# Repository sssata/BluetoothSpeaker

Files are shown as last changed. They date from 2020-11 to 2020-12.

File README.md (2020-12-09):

# BluetoothSpeaker
A diy omnidirectional bluetooth speaker.

Completed 2020.

# Features
- 2-Way speaker with passive radiator design for bass response down to 40 Hz
- Woofer: Tang Band W5-1138SMF 5" Paper Cone Subwoofer
- Tweeter: Dayton Audio DC28F-8 1-1/8" Silk Tweeter
- DSP equalizer for tuned frequency response and FIR crossover for phase coherence
- Omnidirectional radiaton pattern for consistent sound in different rooms/environments
- Battery Powered with Battery Level indicator
- Charging via USB-C PD

# Gallery
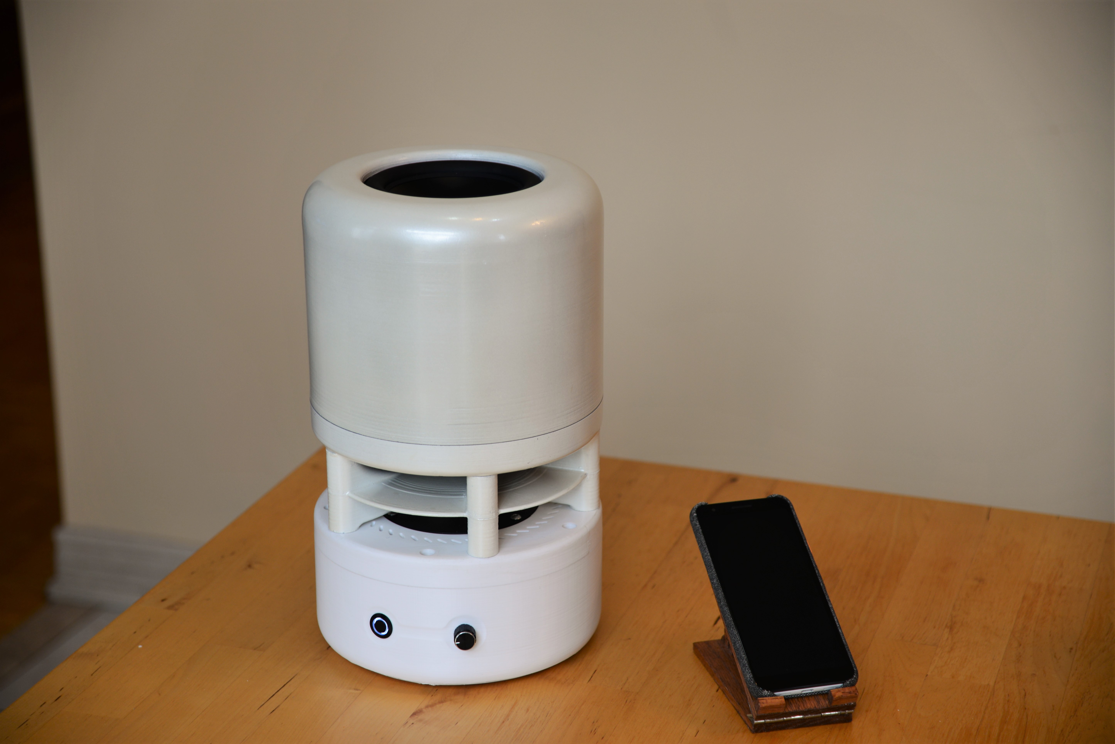
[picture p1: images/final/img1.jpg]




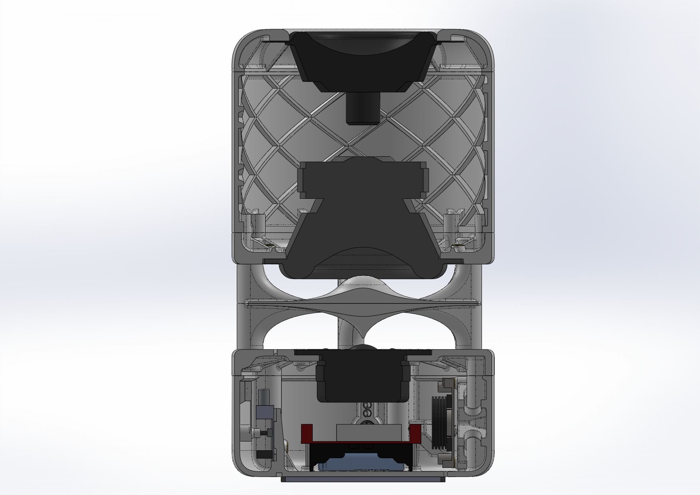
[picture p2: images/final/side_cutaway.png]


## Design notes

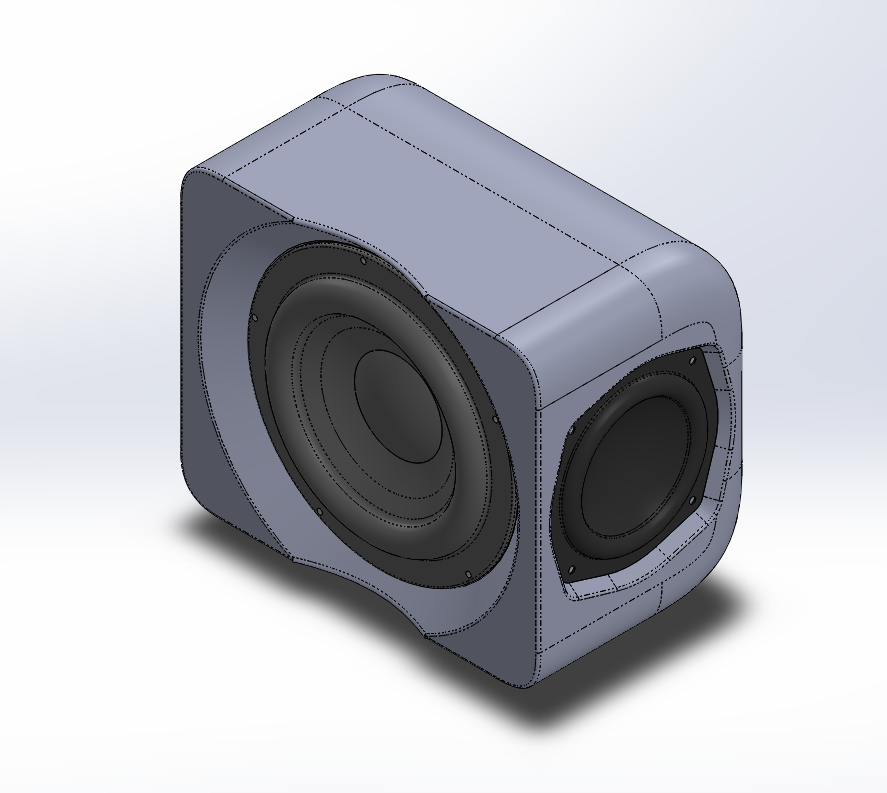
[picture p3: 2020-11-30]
images/concept/concept2.png

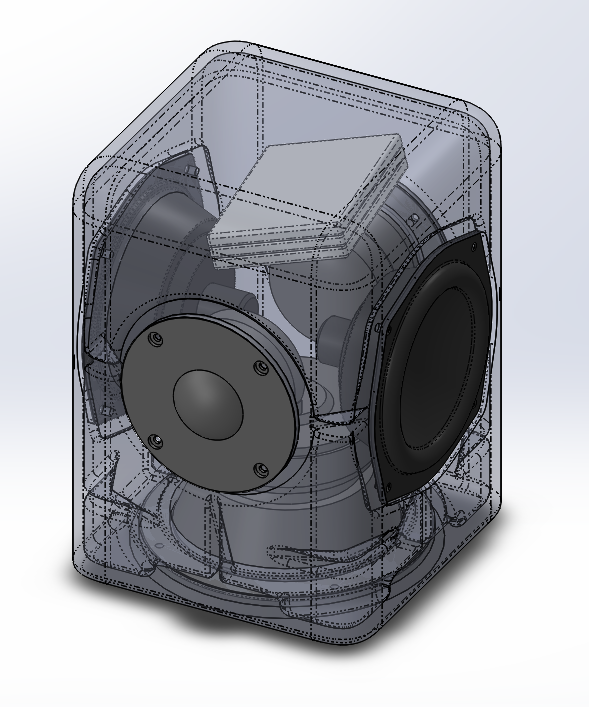
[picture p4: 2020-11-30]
images/concept/concept1.png

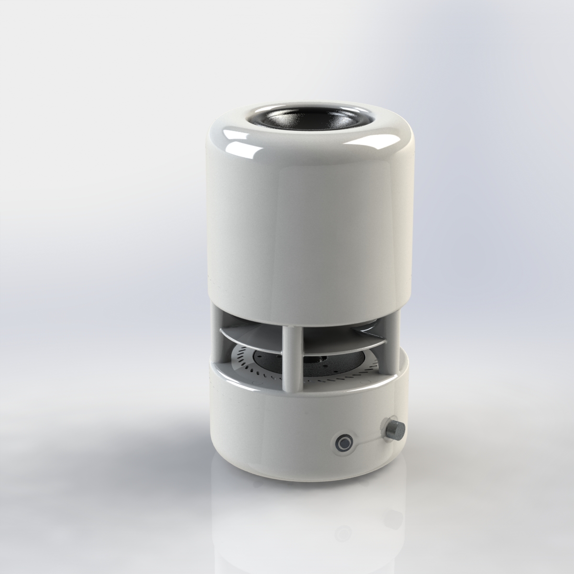
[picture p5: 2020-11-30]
images/final/full.JPG

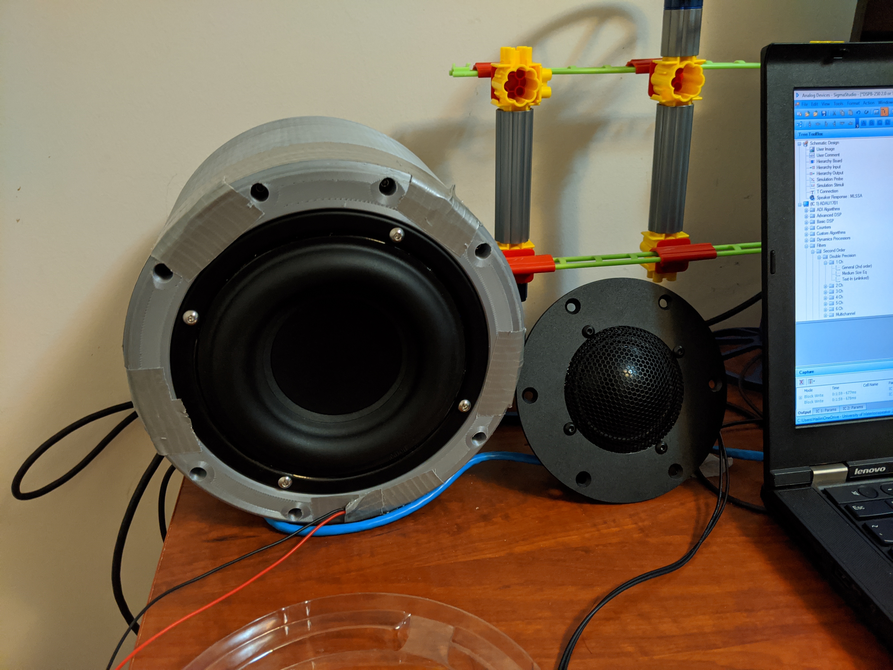
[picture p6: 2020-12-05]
images/prototyping/woofer.jpg

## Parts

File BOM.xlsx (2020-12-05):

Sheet: 900
Assembly Number | 900
Assembly Name | Top Level Assembly
BOM
Part Number | Part Name | Qty
003 | reflector | 1
800 | base assembly | 1
801 | tweeter plate assembly | 1
802 | woofer plate assembly | 1
803 | woofer cover assembly | 1
112 | M5x80 SHCS | 5
156 | base pad | 1
121 | M4x20 SHCS | 10
122 | M5x20 SHCS | 5

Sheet: 800
Assembly Number | 800
Assembly Name | Base Assembly
BOM
Part Number | Part Name | Qty
001 | Base | 1
151 | U16F2 Switch | 1
152 | U8M Switch | 1
153 | Volume Knob | 1
154 | 5mm LED | 4
100 | M3 Insert | 7
150 | 10K POT | 1
300 | Bluetooth Board | 1
301 | Dayton Audio DSPB-250 | 1
302 | Dayton Audio KAB-BE | 1
021 | USBC Port Cover | 1
020 | USBC Port | 1
118 | M3x12 BHCS | 6

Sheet: 801
Assembly Number | 801
Assembly Name | Tweeter Plate Assembly
BOM
Part Number | Part Name | Qty
002 | tweeter plate | 1
007 | Tweeter Plate Plug | 5
401 | Dayton Audio DC28F-8 | 1
102 | M5 Insert | 5
115 | M5 Nut | 3
116 | M4x12 BHCS | 3

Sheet: 802
Assembly Number | 802
Assembly Name | Tweeter Plate Assembly
BOM
Part Number | Part Name | Qty
011 | Woofer Cover Bottom | 1
400 | Dayton Audio 105-PR | 1
101 | M4 Insert | 10
117 | M4x6 BHCS | 4

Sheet: 803
Assembly Number | 803
Assembly Name | Tweeter Plate Assembly
BOM
Part Number | Part Name | Qty
010 | Woofer Plate | 1
402 | Tang Band W5-1138SMF | 1
101 | M4 Insert | 4
102 | M5 Insert | 5
116 | M4x12 BHCS | 4

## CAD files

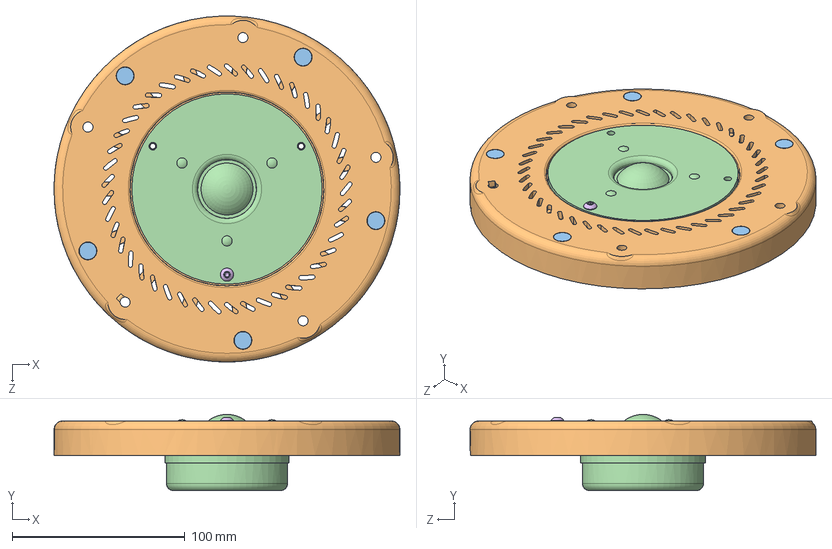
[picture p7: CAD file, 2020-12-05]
CAD/801 tweeter plate assy.SLDASM
200.0 x 44.1 x 200.0 mm
102 M5 Insert x 5
002 tweeter plate
007 tweeter plate plug x 5
401 Dayton Audio DC28F-8 tweeter
115 M4 NUT x 3
socket button head cap screw_am

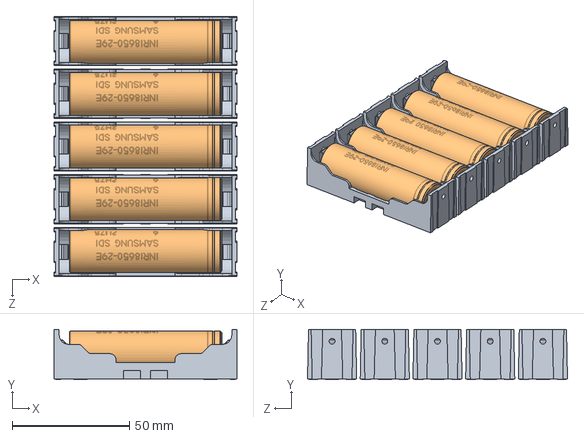
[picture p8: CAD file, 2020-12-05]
CAD/302 Dayton Audio KAB-BE Battery Board.SLDASM
77.9 x 21.4 x 111.0 mm
single 18650 battery holder x 5
Samsung INR18650-29R x 5

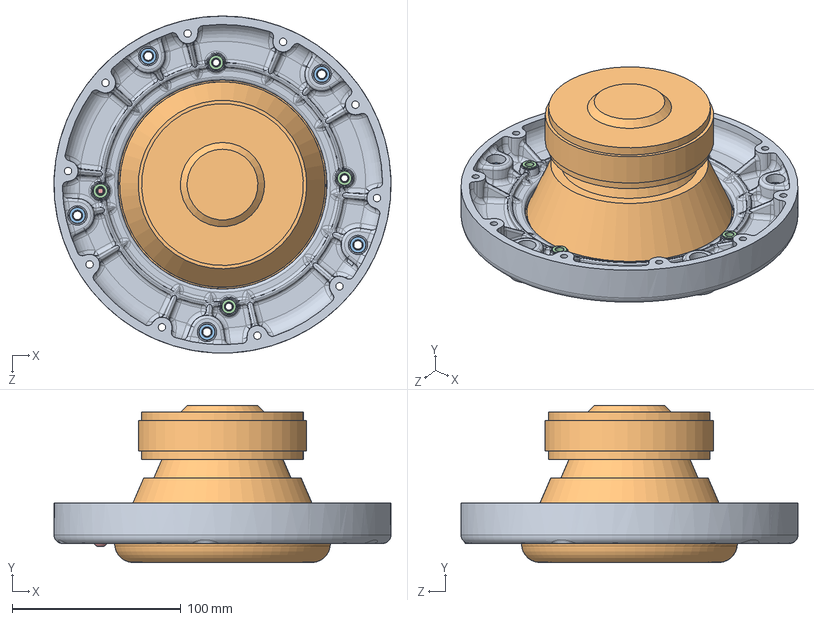
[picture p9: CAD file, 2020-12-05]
CAD/803 woofer plate assy.SLDASM
200.0 x 93.2 x 199.9 mm
010 top woofer plate
402 Tang Band W5-1138SMF
102 M5 Insert x 5
101 M4 Insert x 4
socket button head cap screw_am

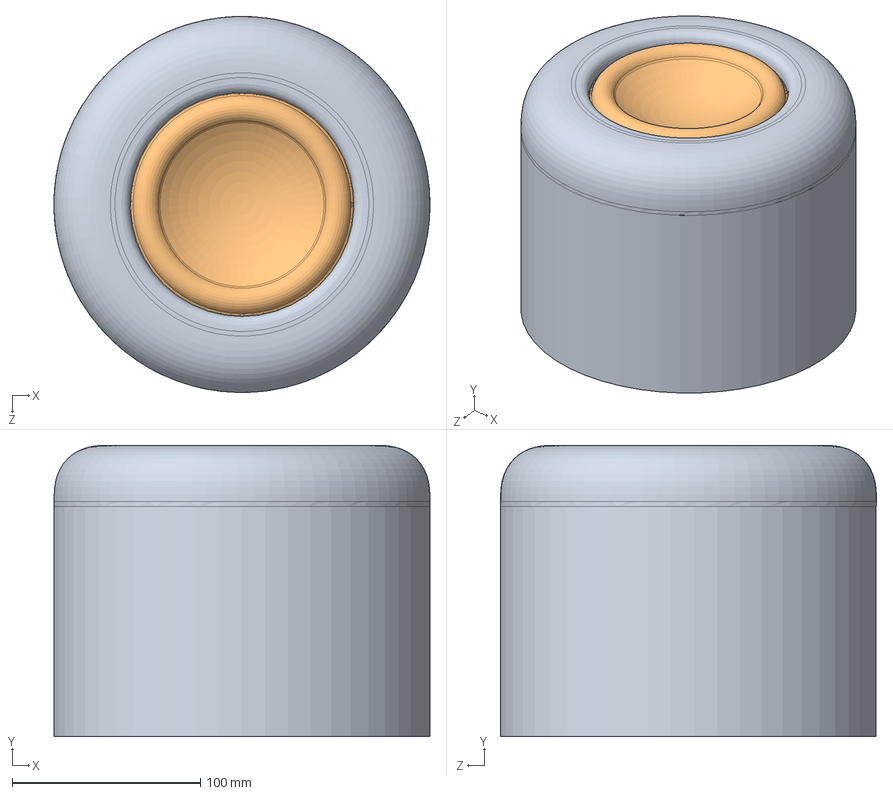
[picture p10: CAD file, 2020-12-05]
CAD/802 woofer cover assy.SLDASM
200.0 x 155.0 x 200.0 mm
011 woofer cover bottom
400 Dayton Audio 105-PR 4inch
101 M4 Insert x 10
socket button head cap screw_am x 4

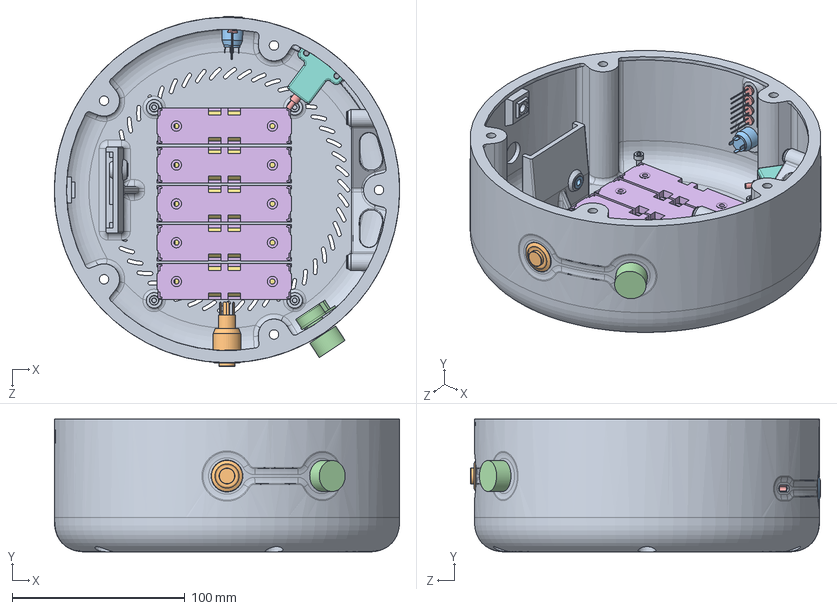
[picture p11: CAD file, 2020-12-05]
CAD/800 base assembly.SLDASM
200.0 x 77.0 x 202.7 mm
001 Base
151 U16F2 Switch
100 M3 Insert x 7
150 10K Pot
020 USBC port
single 18650 battery holder x 5
Samsung INR18650-29R x 5
021 USBC port cover
113 M3x25 SHCS x 4
114 M3 NUT x 4
152 U8M Switch
153 Volume Knob
154 5mm LED x 4

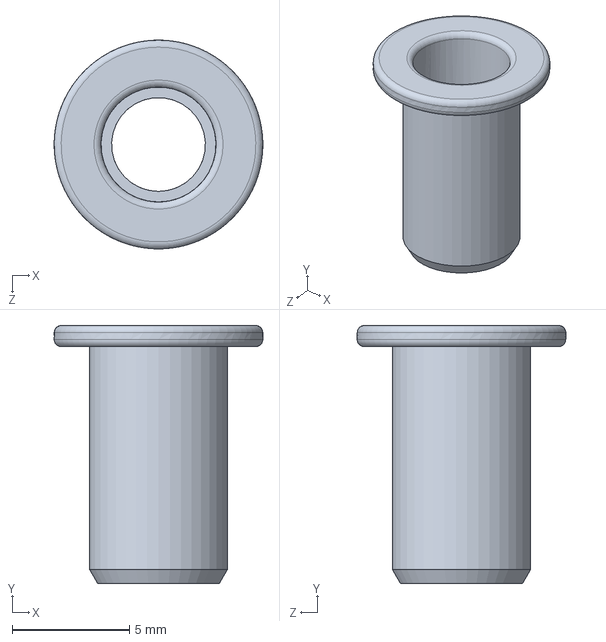
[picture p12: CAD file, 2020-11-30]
CAD3/101 M4 Insert.SLDPRT
8.90 x 11.0 x 8.90 mm

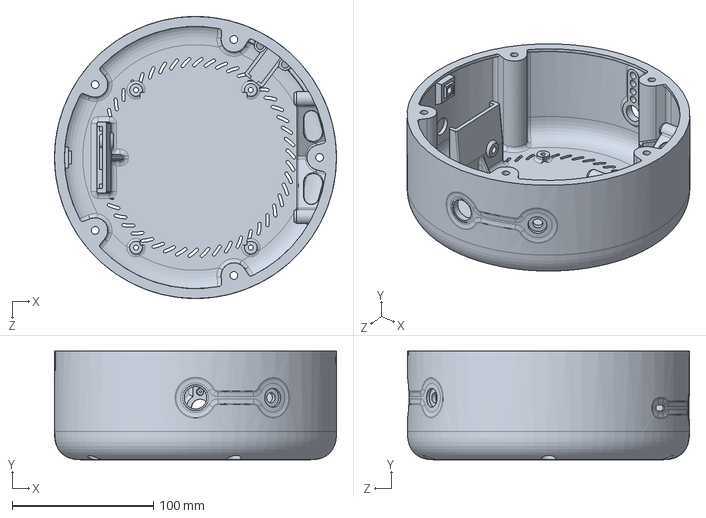
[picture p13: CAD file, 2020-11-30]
CAD3/001 Base.SLDPRT
200.0 x 77.0 x 200.0 mm

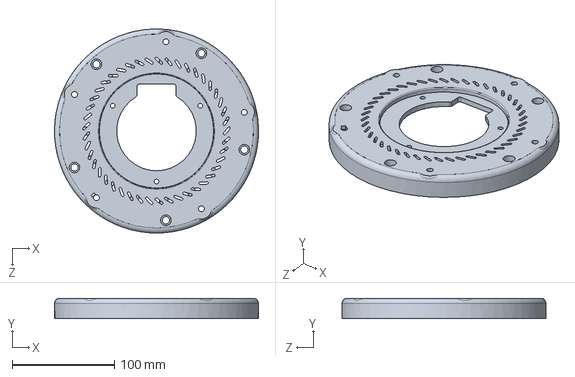
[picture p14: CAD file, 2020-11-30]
CAD3/002 tweeter plate.sldprt
200.0 x 20.0 x 200.0 mm

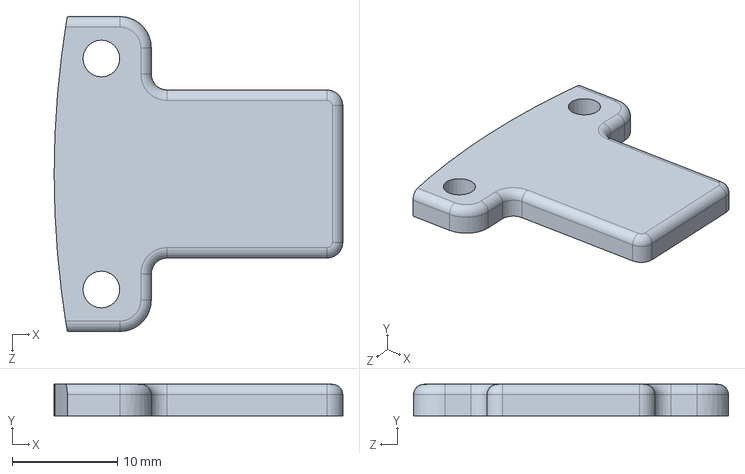
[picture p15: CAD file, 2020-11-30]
CAD3/021 USBC port cover.SLDPRT
27.5 x 3.00 x 30.0 mm

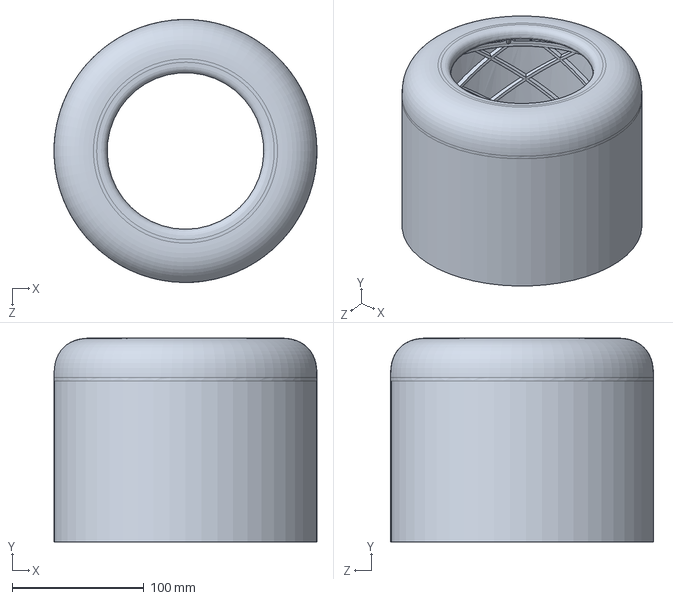
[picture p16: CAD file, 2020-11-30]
CAD3/011 woofer cover bottom.SLDPRT
200.0 x 155.0 x 200.0 mm

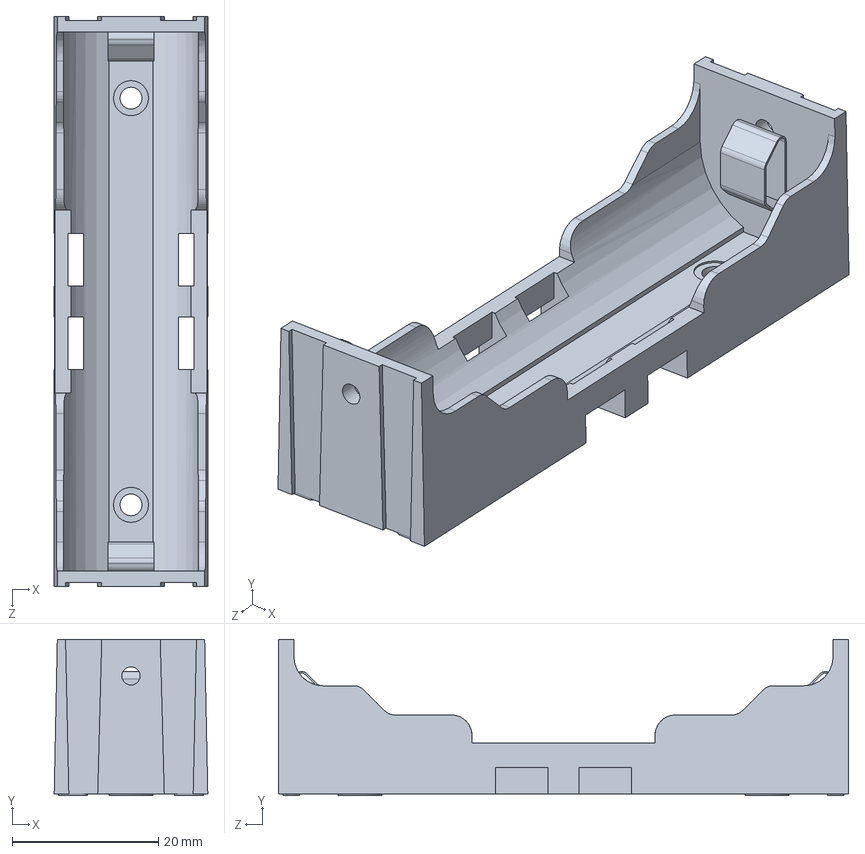
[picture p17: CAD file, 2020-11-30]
CAD3/single 18650 battery holder.SLDPRT
21.0 x 21.4 x 77.9 mm

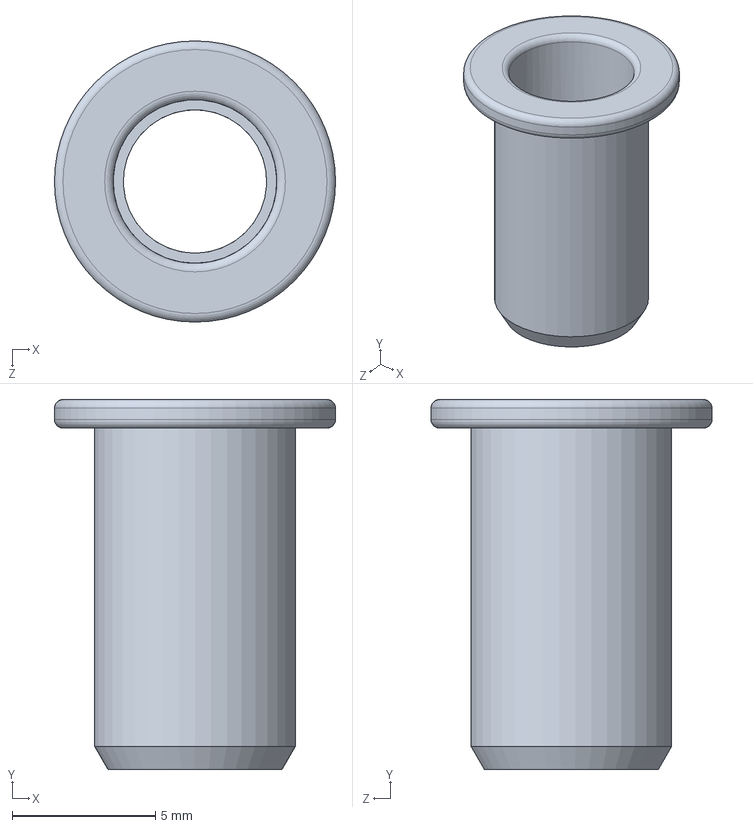
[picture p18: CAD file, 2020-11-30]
CAD/102 M5 Insert.SLDPRT
9.80 x 12.9 x 9.80 mm

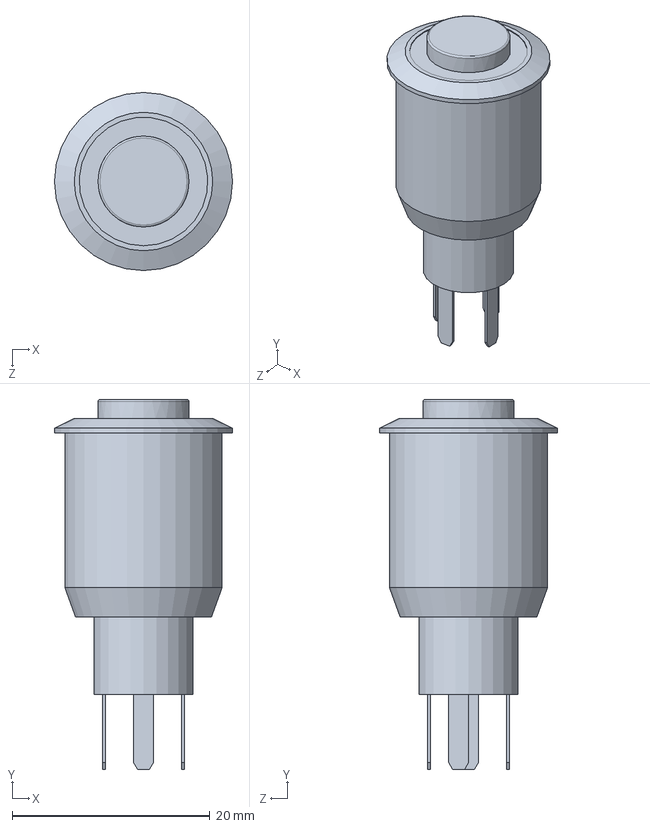
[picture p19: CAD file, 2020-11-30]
CAD3/151 U16F2 Switch.SLDPRT
18.0 x 37.4 x 18.0 mm

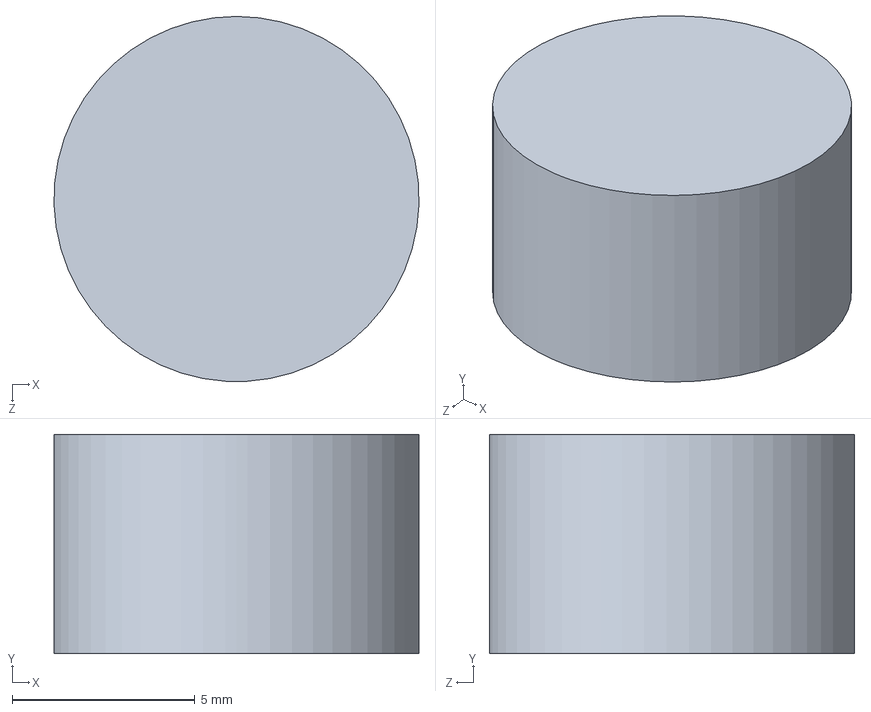
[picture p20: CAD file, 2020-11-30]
CAD/007 tweeter plate plug.SLDPRT
10.00 x 6.00 x 10.0 mm

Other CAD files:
CAD3/Samsung INR18650-29R.SLDPRT
CAD/020 USBC port.SLDPRT
CAD3/020 USBC port.SLDPRT
CAD/003 reflector.SLDPRT
CAD/006 bluetooth button.SLDPRT
CAD/010 top woofer plate.SLDPRT
CAD/100 M3 Insert.SLDPRT
CAD/112 M5x80 SHCS.SLDPRT
CAD/113 M3x25 SHCS.SLDPRT
CAD/114 M3 NUT.SLDPRT
CAD/115 M4 NUT.SLDPRT
CAD/150 10K Pot.SLDPRT
CAD/152 U8M Switch.SLDPRT
CAD/153 Volume Knob.SLDPRT
CAD/154 5mm LED.SLDPRT
CAD/156 base pad.SLDPRT
CAD/300 Bluetooth board.SLDPRT
CAD/301 Dayton Audio DSPB-250 Amplifier Board.SLDPRT
CAD/301 Dayton Audio KAB-BE PCB.SLDPRT
CAD/3D Print STL/007 tweeter plate plug.STL
CAD/3D Print STL/021 USBC port cover.STL
CAD/400 Dayton Audio 105-PR 4inch.SLDPRT
CAD/401 Dayton Audio DC28F-8 tweeter.SLDPRT
CAD/402 Tang Band W5-1138SMF.SLDPRT
CAD/Samsung INR18650-29R.SLDPRT
CAD/socket button head cap screw_am.sldprt
CAD/socket head cap screw_am.sldprt
CAD3/006 bluetooth button.SLDPRT
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

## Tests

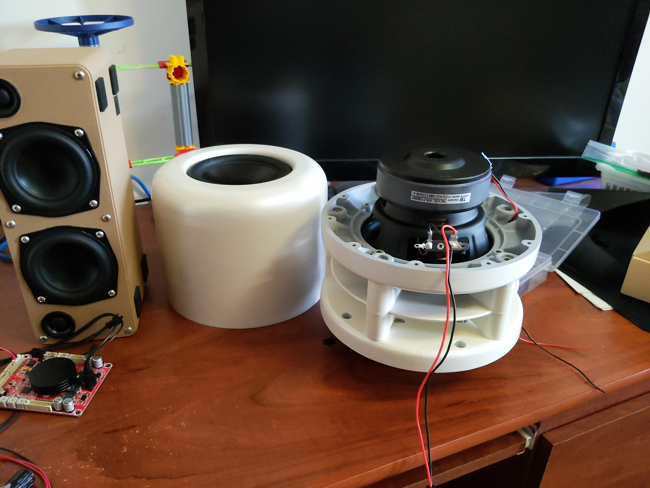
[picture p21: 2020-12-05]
images/prototyping/assemblyTest.jpg

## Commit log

2020-12-05 restructured CAD
    [001 Base.SLDPRT, 002 tweeter plate.sldprt, 003 reflector.SLDPRT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]
2020-12-05 renamed folder
    [001 Base.SLDPRT, 002 tweeter plate.sldprt, 003 reflector.SLDPRT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]
2020-12-05 added STLs
    [007 tweeter plate plug.STL, 021 USBC port cover.STL]
